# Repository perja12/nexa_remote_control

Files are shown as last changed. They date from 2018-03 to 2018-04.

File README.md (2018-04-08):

# Nexa remote control

Hardware and firmware for creating custom Nexa remote control. This project uses ATtiny85 and a STX882 ASK module as the RF module. It can be used to control various Nexa devices that uses 433 MHz.

One of the goals was to minimize the power usage so that it can run from a battery like CR2032.

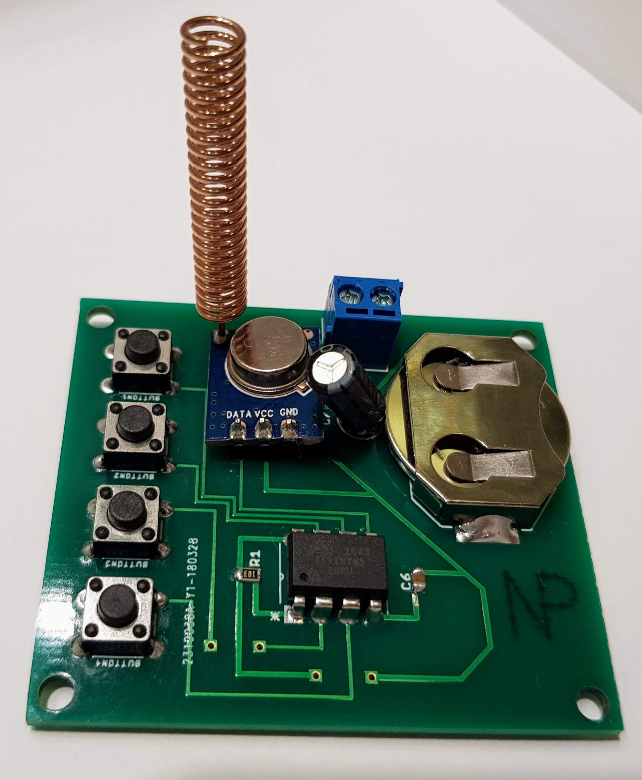
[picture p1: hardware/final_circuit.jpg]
Final circuit


## Installing NexaCtrl library

The firmware uses the NexaCtrl library and this be installed in your Arduino folder:
```bash
cd ~/Arduino/libraries
git clone git@github.com:calle-gunnarsson/NexaCtrl.git
```

## Building the firmware and uploading it to ATtiny85

To build the firmware, use the provided Makefile:
```bash
make
```

This project uses an Arduino Uno to program the ATtiny85:
https://create.arduino.cc/projecthub/arjun/programming-attiny85-with-arduino-uno-afb829

Once you have the setup ready you can upload the firmware with the command:
```bash
make upload
```

# Hardware

See the hardware folder for schematic and board layout files from Eagle. And also the list of parts. Note that it can use either a coin cell battery (CR2032) or f.ex. 2xAA batteries connected to the battery terminal.

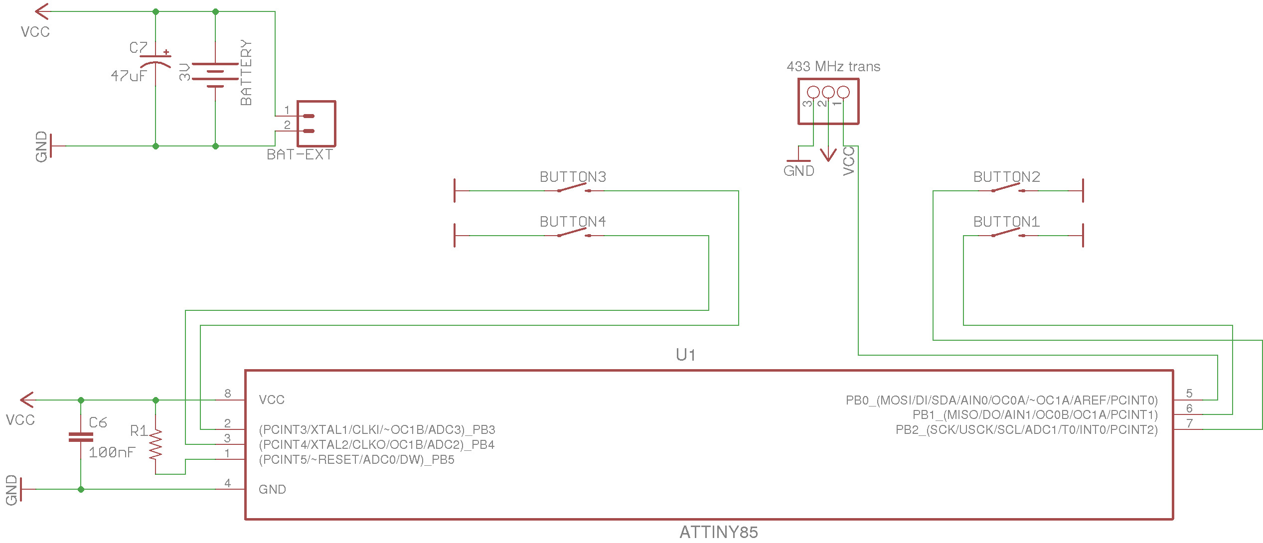
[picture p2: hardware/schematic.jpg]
Schematic


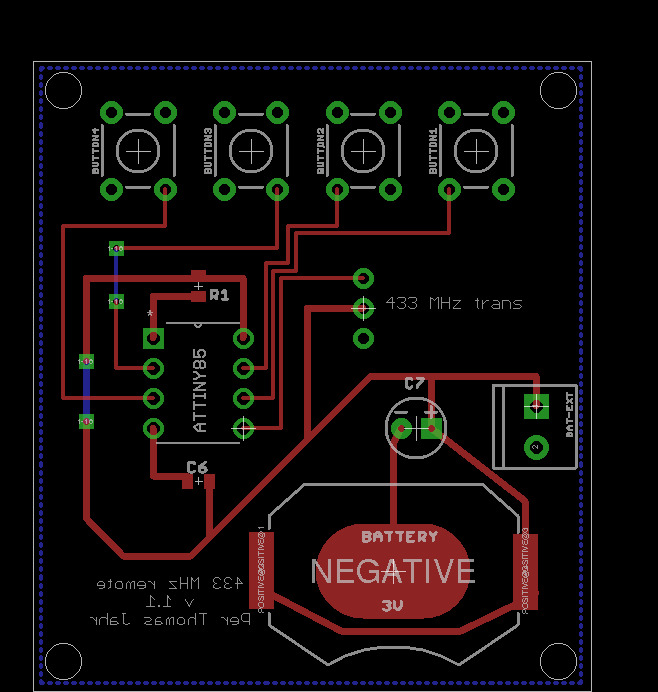
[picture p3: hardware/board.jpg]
Board


The RF module used here is https://www.aliexpress.com/item/10pcs-lot-ASK-RF-module-433mhz-transmitter-module/32238392004.html

# Resources
* Nexa devices: https://www.nexa.se/vara-produkter/system-nexa/mottagare-paav
* Pin change interrupt on ATtiny85:
    * https://thewanderingengineer.com/2014/08/11/pin-change-interrupts-on-attiny85/
    * https://embeddedthoughts.com/2016/06/06/attiny85-introduction-to-pin-change-and-timer-interrupts/
    * http://gammon.com.au/interrupts
* ATtiny85 datasheet: http://www.atmel.com/images/atmel-2586-avr-8-bit-microcontroller-attiny25-attiny45-attiny85_datasheet.pdf
* NexaCtrl library: https://github.com/calle-gunnarsson/NexaCtrl

# How to pair with a Nexa device

In order to use the controller with a device (like a plug-in receiver) you need to either find the existing id of your device and use that in `CONTROLLER_ID`. Or you can configure the device to listen for the id set in `CONTROLLER_ID` (self learning). Disconnect the device from mains and then plug it back in. Then, within 5 seconds, press the "on" button on the controller. You should then hear the relay switching a couple of times. If nothing happens, the device memory can be full and you have to reset it with a "group off" command during that 5 seconds start up. You probably have to do this with a paired remote. Consult the user manual of the device.

# Questions or found a bug?

Please raise an [issue](https://github.com/perja12/nexa_remote_control/issues/new) or a new [pull request](https://github.com/perja12/nexa_remote_control/pulls) if you have some code changes.

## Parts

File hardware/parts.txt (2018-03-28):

Part     Value          Device                          Package                  Library                       Sheet

BAT-EXT                 CONN_023.5MM                    SCREWTERMINAL-3.5MM-2    SparkFun-Connectors           1
BATTERY  3V             BATTERY-20MM_SMD_4LEGS          BATTCON_20MM_4LEGS       SparkFun-Batteries            1
BUTTON1                 MOMENTARY-SWITCH-SPST-PTH-6.0MM TACTILE_SWITCH_PTH_6.0MM SparkFun-Switches             1
BUTTON2                 MOMENTARY-SWITCH-SPST-PTH-6.0MM TACTILE_SWITCH_PTH_6.0MM SparkFun-Switches             1
BUTTON3                 MOMENTARY-SWITCH-SPST-PTH-6.0MM TACTILE_SWITCH_PTH_6.0MM SparkFun-Switches             1
BUTTON4                 MOMENTARY-SWITCH-SPST-PTH-6.0MM TACTILE_SWITCH_PTH_6.0MM SparkFun-Switches             1
C6       100nF          0.33UF/330NF-0805-50V-10%       0805                     SparkFun-Capacitors           1
C7       47uF           10UF-POLAR-RADIAL-2.5MM-25V-20% CPOL-RADIAL-2.5MM-5MM    SparkFun-Capacitors           1
JMR-TX-1 433 MHz trans  PINHD-1X3CB                     1X03-CLEANBIG            adafruit                      1
R1       10K            0.3OHM-0805-1/8W-1%             0805                     SparkFun-Resistors            1
U1       ATTINY85       ATTINY85-20PU                   DIP254P762X533-8         Atmel_By_element14_Batch_1-00 1

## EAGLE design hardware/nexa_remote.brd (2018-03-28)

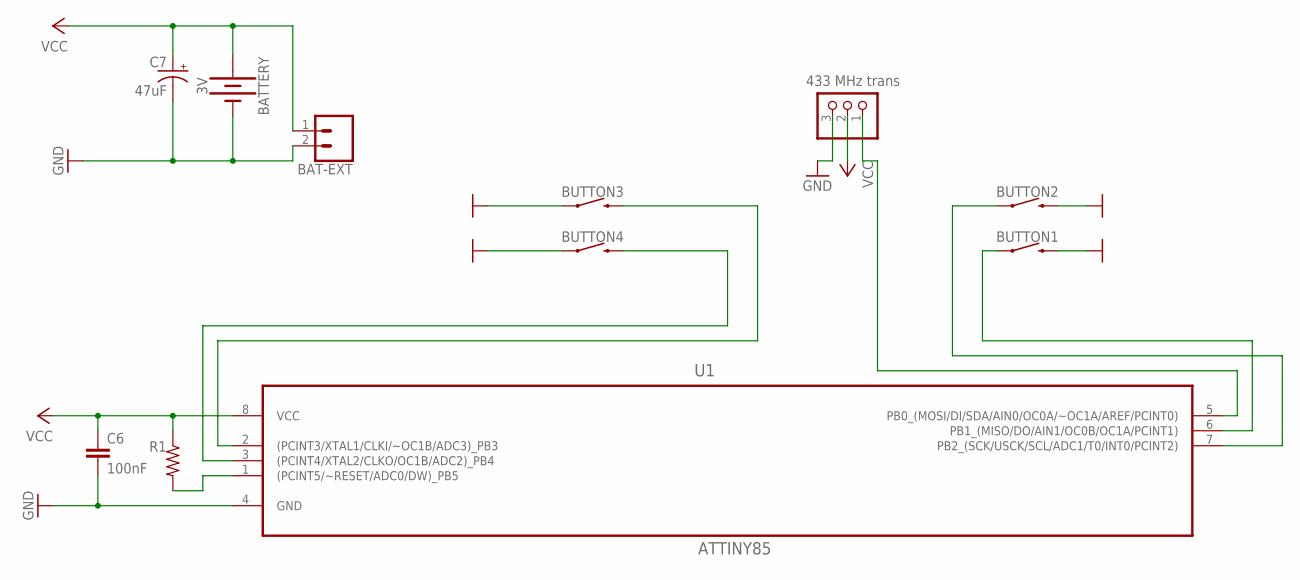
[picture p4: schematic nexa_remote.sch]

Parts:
BAT-EXT: CONN_023.5MM; SCREWTERMINAL-3.5MM-2
BATTERY: 3V; BATTCON_20MM_4LEGS
BUTTON1, BUTTON2, BUTTON3, BUTTON4: MOMENTARY-SWITCH-SPST-PTH-6.0MM; TACTILE_SWITCH_PTH_6.0MM
C6: 100nF; 0805
C7: 47uF; CPOL-RADIAL-2.5MM-5MM
JMR-TX-1: 433 MHz trans; 1X03-CLEANBIG
R1: 10K; 0805
U1: ATTINY85; DIP254P762X533-8

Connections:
GND: BAT-EXT.2, BATTERY.NEGATIVE (-), BUTTON1.3 (2), BUTTON2.3 (2), BUTTON3.1, BUTTON4.1, C6.2, C7.2 (-), JMR-TX-1.3, U1.4 (GND)
unnamed: R1.2, U1.1 ((PCINT5/~RESET/ADC0/DW)_PB5)
unnamed: JMR-TX-1.1, U1.5 (PB0_(MOSI/DI/SDA/AIN0/OC0A/~OC1A/AREF/P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)
unnamed: BUTTON1.1, U1.6 (PB1_(MISO/DO/AIN1/OC0B/OC1A/PCINT1))
unnamed: BUTTON3.3 (2), U1.2 ((PCINT3/XTAL1/CLKI/~OC1B/ADC3)_PB3)
unnamed: BUTTON4.3 (2), U1.3 ((PCINT4/XTAL2/CLKO/OC1B/ADC2)_PB4)
unnamed: BUTTON2.1, U1.7 (PB2_(SCK/USCK/SCL/ADC1/T0/INT0/PCINT2))
VCC: BAT-EXT.1, BATTERY.POSITIVE@1 (+), BATTERY.POSITIVE@2 (+), BATTERY.POSITIVE@3 (+), BATTERY.POSITIVE@4 (+), C6.1, C7.1 (+), JMR-TX-1.2, R1.1, U1.8 (VCC)

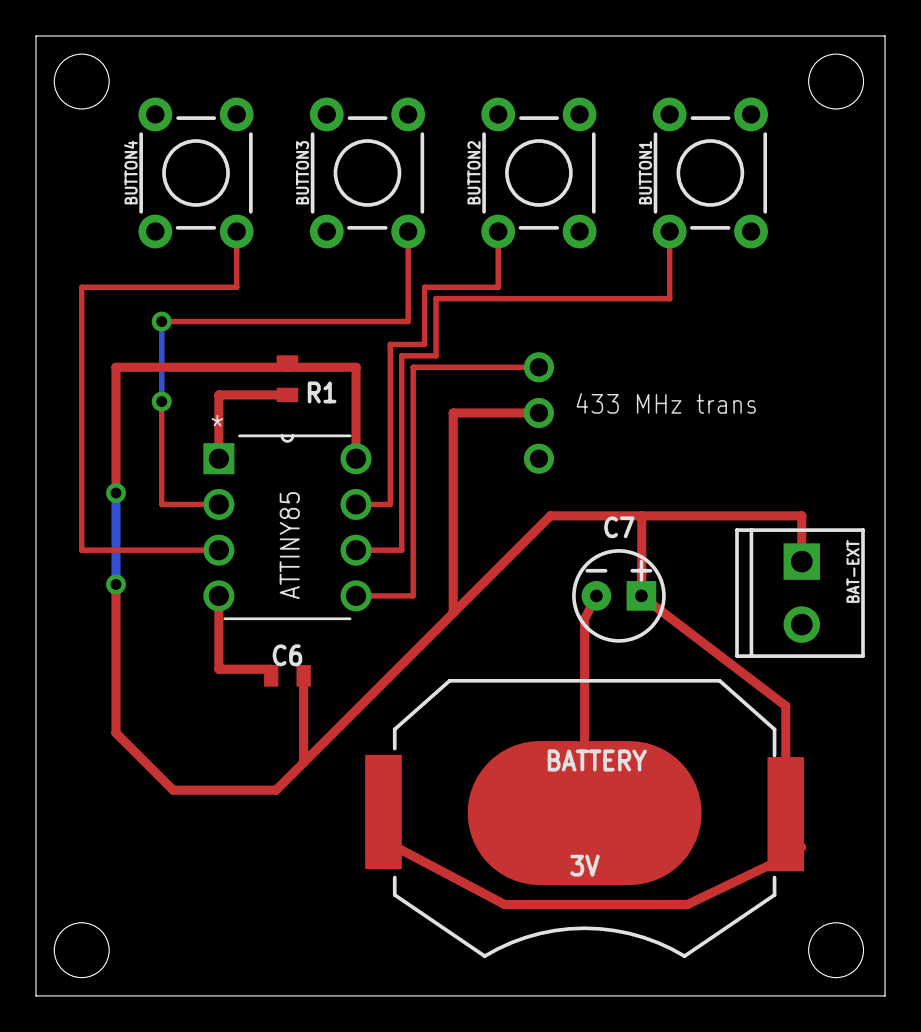
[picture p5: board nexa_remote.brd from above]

Board: 2 copper layers, 47.2 x 53.3 mm, 11 parts (0 on the bottom side), 8 nets.

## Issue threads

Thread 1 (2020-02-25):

(Not Issue)Power consumption of this hardware?

maharshi114, 2020-02-25:
Hello,
I appreciate you for this nice project.
Can you share the following information for the reference only?

1. Battery Type?
2. Battery voltage range?
3. Current consumption in active mode?
4. Current consumption in sleep mode?
5. The total life of a battery?

perja12, 2020-02-25:
Thanks!

The battery I use for this project is a CR2032 (f.ex. https://data.energizer.com/pdfs/cr2032.pdf) nominal voltage of 3.0V and capacity of 235 mAh.

The active current consumption when the circuit is transmitting is about 3.7 mA and the sleep current is around 0.17 uA. The total life of the battery depends on how much it is used and I haven't measured the average current consumption over a longer time when in use. But for me it has lasted for years already. The active period only lasts for 250 ms or so before it goes back to sleep.

maharshi114, 2020-02-26:
Great.  Thank you for the quick replay.

Closed 2020-02-26.

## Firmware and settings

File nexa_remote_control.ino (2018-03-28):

#include <NexaCtrl.h>
#include <avr/power.h>
#include <avr/sleep.h>

#define TX_PIN 0 // Same as PB0
#define RX_PIN 2 // Not used.

#define CMD_NONE 0
#define CMD_1    1
#define CMD_2    2
#define CMD_3    3
#define CMD_4    4

// Send commands to Nexa controller with 433 MHz RF module and
// ATtiny85 with minimal power consumption.
//
// A change interrupt wakes the mcu and checks which button that was
// pressed. There is no hardware for debouncing the buttons since we
// only process the first interrupt (by temporarily disabling
// interrupts) and uses delay(100) before enabling interrupts again.

// Pinout for ATtiny85:
// RESET PB5 (5/A0) *o**** VCC
//       PB3 (3/A3) ****** PB2 (2/A1)
//       PB4 (4/A2) ****** PB1 (1)
//              GND ****** PB0 (0)

// 26 bit controller id assigned to each Nexa device.
const static unsigned long CONTROLLER_ID = 9610883;

// 4 bit device id.
const static unsigned int DEVICE_1 = 0;
const static unsigned int DEVICE_2 = 1;

NexaCtrl nexaCtrl(TX_PIN, RX_PIN);

volatile int cmd = CMD_NONE;

ISR(PCINT0_vect) {
    cli();

    if (!bit_is_set(PINB, PB1)) {
        cmd = CMD_1;
    }
    if (!bit_is_set(PINB, PB2)) {
        cmd = CMD_2;
    }
    if (!bit_is_set(PINB, PB3)) {
        cmd = CMD_3;
    }
    if (!bit_is_set(PINB, PB4)) {
        cmd = CMD_4;
    }
}

void setup() {
    set_sleep_mode(SLEEP_MODE_PWR_DOWN);

    // Turn off ADC to save power.
    ADCSRA &= ~ bit(ADEN);

    pinMode(PB1, INPUT_PULLUP);
    pinMode(PB2, INPUT_PULLUP);
    pinMode(PB3, INPUT_PULLUP);
    pinMode(PB4, INPUT_PULLUP);

    // Configure pin change interrupt.
    PCMSK  |= _BV (PCINT1);
    PCMSK  |= _BV (PCINT2);
    PCMSK  |= _BV (PCINT3);
    PCMSK  |= _BV (PCINT4);
    GIFR   |= bit (PCIF);    // clear any outstanding interrupts
    GIMSK  |= bit (PCIE);    // enable pin change interrupts
}

void loop() {
    // Set TX_PIN to INPUT in order to save power.
    pinMode(TX_PIN, INPUT);

    // Enable interrupts again, go to sleep and wait for intterrupt.
    sei();
    go_to_sleep();

    // Wakes up here.
    pinMode(TX_PIN, OUTPUT);

    switch (cmd) {
    case CMD_1:
        nexaCtrl.DeviceOn(CONTROLLER_ID, DEVICE_1);
        break;
    case CMD_2:
        nexaCtrl.DeviceOff(CONTROLLER_ID, DEVICE_1);
        break;
    case CMD_3:
        nexaCtrl.DeviceOn(CONTROLLER_ID, DEVICE_2);
        break;
    case CMD_4:
        nexaCtrl.DeviceOff(CONTROLLER_ID, DEVICE_2);
        break;
    }
    cmd = CMD_NONE;

    // Avoid getting a new interrupt because of button bounce.
    delay(100);
}

void go_to_sleep() {
    power_all_disable();  // power off ADC, Timer 0 and 1, serial interface
    sleep_enable();
    sleep_cpu();
    sleep_disable();
    power_all_enable();   // power everything back on
}

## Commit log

2018-03-28 New firmware for version 1.1 and updated instructions.
    [nexa_remote.brd, nexa_remote.sch]
2018-04-08 Add image of final circuit.

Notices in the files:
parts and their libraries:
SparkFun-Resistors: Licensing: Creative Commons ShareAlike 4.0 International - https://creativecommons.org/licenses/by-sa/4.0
